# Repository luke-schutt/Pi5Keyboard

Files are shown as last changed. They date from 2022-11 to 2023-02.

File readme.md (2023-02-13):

# Pi5 Keyboard

A monoblock split 38-key keyboard inspired by the [ChocV](https://github.com/brickbots/chocV).

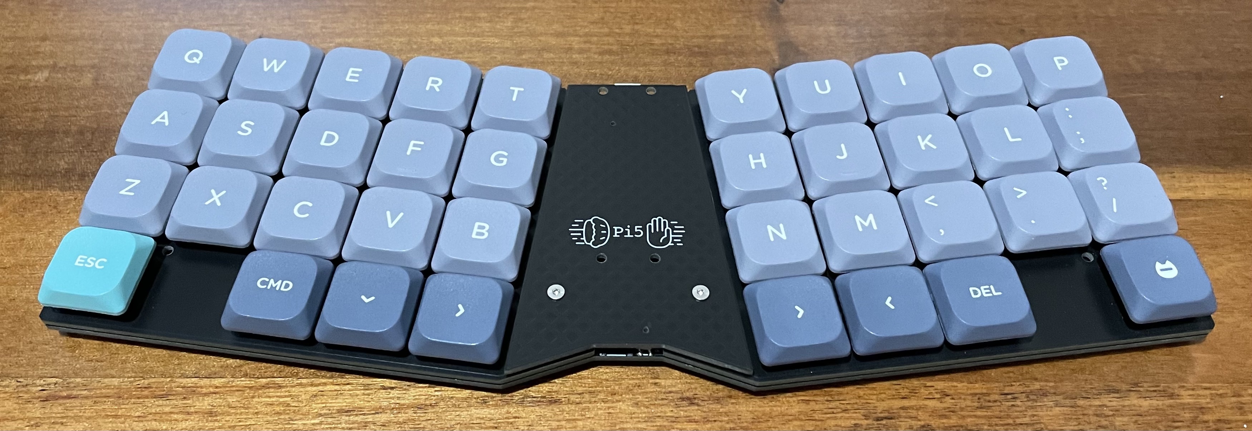
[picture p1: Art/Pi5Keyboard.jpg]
Keyboard


## Design

The keyboard consists of two boards, the main PCB and a mounting plate, and and optional MCU cover. The switches are on a 19x19mm grid with the footprint supporting Kailh Choc V1, V2, Gateron low profile, and MX switches.

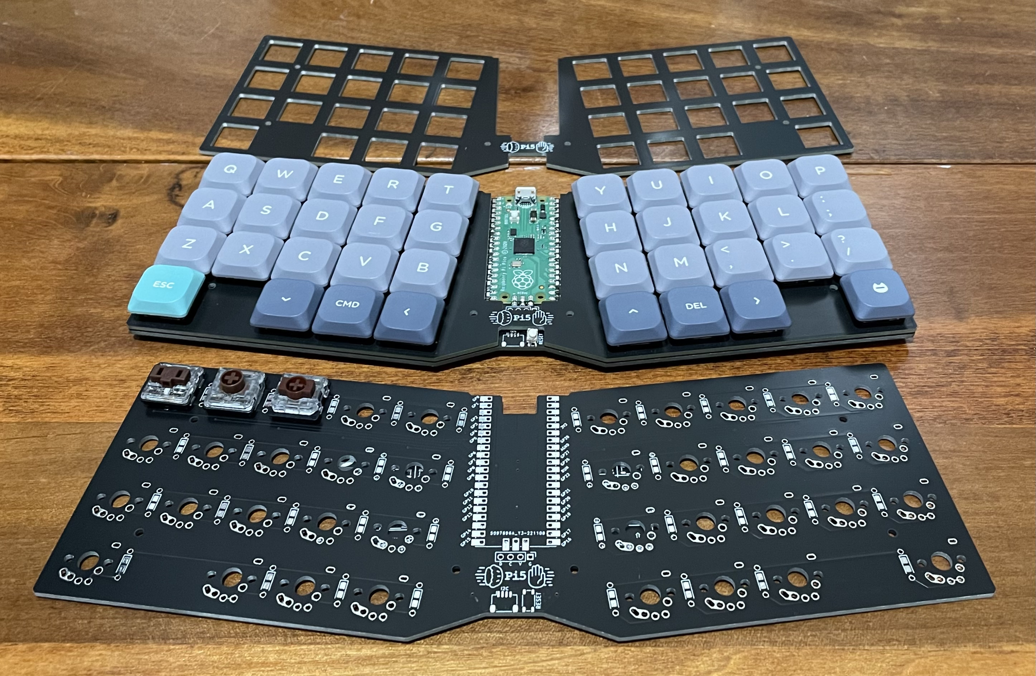
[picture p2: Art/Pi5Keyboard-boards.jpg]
Keyboard boards


The bottom of the board features footprints for a convenient reset switch and a JST connector with 3.3v and I2C data that (again, untested) should support [Qwiic](https://www.sparkfun.com/qwiic) or [STEMMA QT](https://learn.adafruit.com/introducing-adafruit-stemma-qt/what-is-stemma-qt) accessories.

The spacing between the PCB and plate with V2 Choc switches doesn't allow for SMD parts. Fortunately the diode footprint also allows though-hole components so they can be soldered under the PCB.

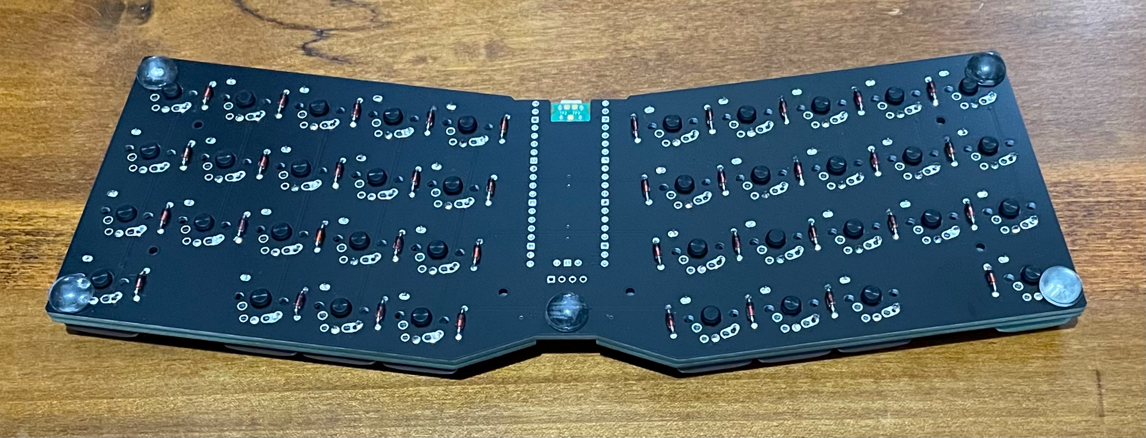
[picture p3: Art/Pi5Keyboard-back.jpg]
Keyboard back


## Build one!

Check out the [gerbers folder](Gerbers/) for zip files that can be uploaded to your PCB manufacturer of your choice.

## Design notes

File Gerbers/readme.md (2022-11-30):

# Gerbers!

Here you can find gerbers and revision history for the Pi5 Keyboard. Git commits are used for the KiCad revisions so if needed checkout the correct commit and make any desired modifications from that.

## Revision 1

Note: _This revision has **not** been tested!_

Revision 1 moves the PCB mounting holes to match the Raspberry Pi Pico's mounting holes and the reset button was moved a bit. Slots for diodes are added to the mounting plate. Holes were moved on the microcontroller cover.

The revision 0 mounting plate is compatible if slots for the diodes aren't desired, however it does have two mounting holes that aren't present. The microcontroller cover was retroactively created for revision 0 with mounting holes matching the Raspberry Pi Pico. Because of this it is also compatible with either design, however the two additional mounting holes were removed and the reset button hole was shifted to match revision 1.

- [main PCB rev1](Pi5-pcb-rev1.zip)
- [mounting plate rev1](Pi5-plate-rev1.zip)
- [controller cover rev1](Pi5-cover-rev1.zip)

## Revision 0

- [main PCB](Pi5-pcb-rev0.zip)
- [mounting plate](Pi5-plate-rev0.zip)
- [controller cover](Pi5-cover-rev0.zip)

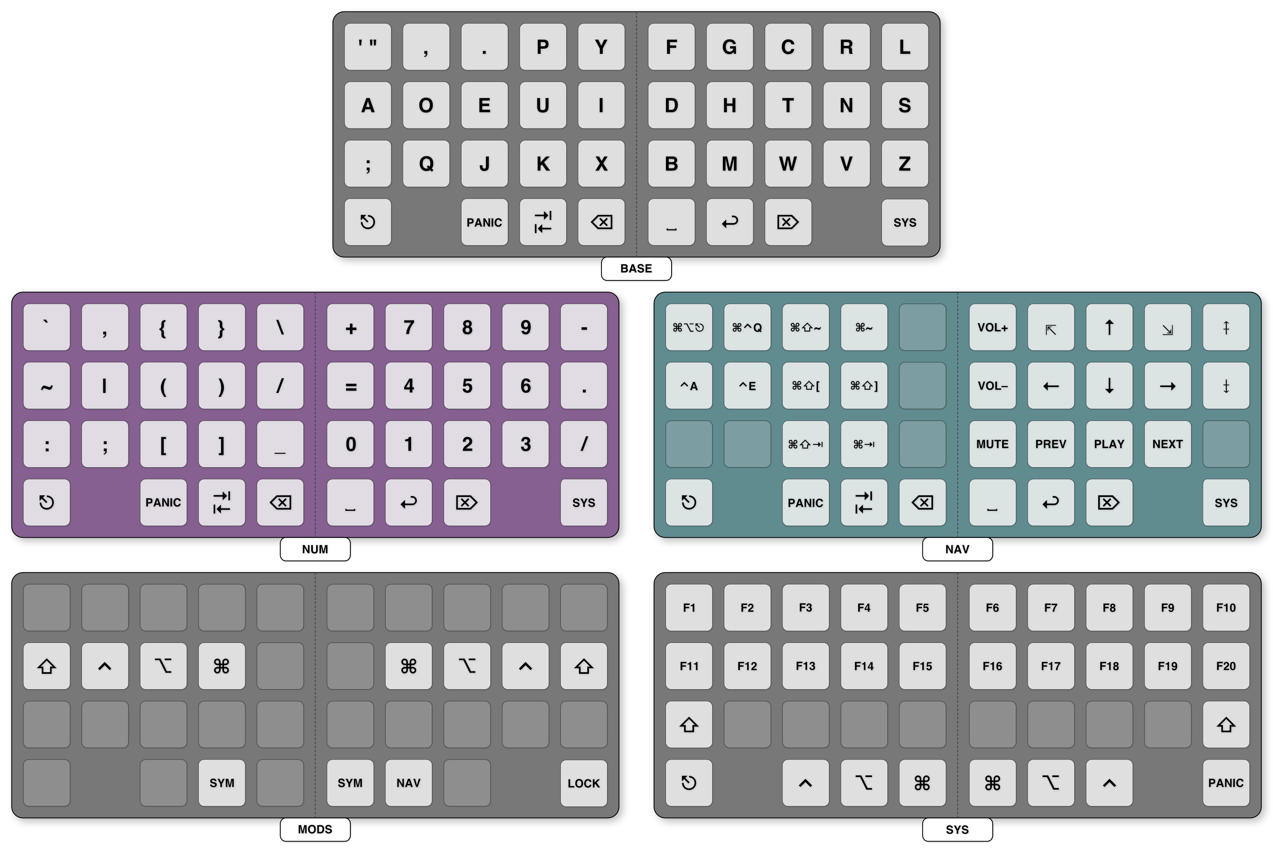
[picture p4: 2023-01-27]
Art/Layout.png

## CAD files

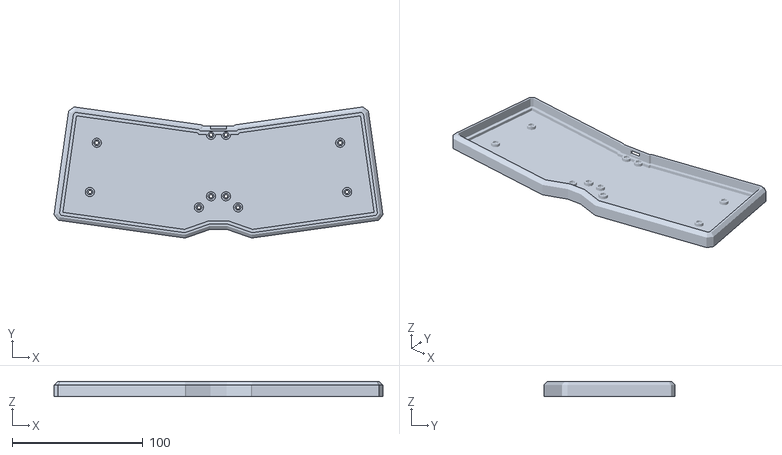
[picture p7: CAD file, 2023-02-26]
Case/case.stl
251.6 x 100.3 x 11.2

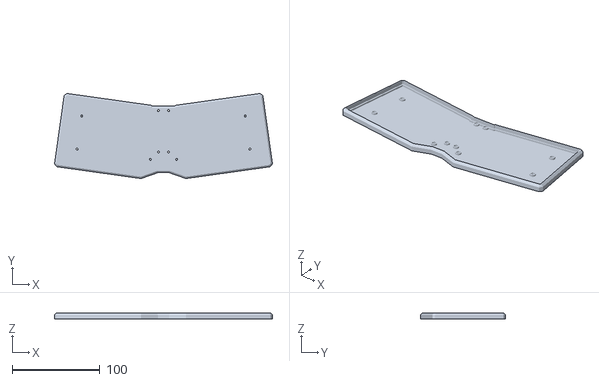
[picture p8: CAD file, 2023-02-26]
stl/case.stl
248.1 x 96.9 x 6.80

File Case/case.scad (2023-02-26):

include <chamfer_extrude.scad>;
$fn = 30;

// Thickness of the PCB.
$pcb_thickness = 7;
// Tolerance for fitting the PCB within the bezel.
$pcb_tolerance = 0.75;
// Width for the PCB lip.
$pcb_lip = 1.75;

// Desired cavity depth, excluding PCB.
$cavity_depth = 2.25;
// Case bottom thickness.
$bottom_thickness = 2;
// Case wall thickness above the PCB lip, at the thickest point.
$wall_thickness = 4;
// Full cavity depth.
cavity_well = $cavity_depth + $pcb_thickness;
// Full case height.
case_height = cavity_well + $bottom_thickness;

// If the top-outer edge should be chamfered.
$chamfer = true;
// The size of the chamfer.
$chamfer_size = 2.5;

// Mounting nut size.
$nut_size = 4.15;
// Mounting nut height.
$nut_height = 1.6;
// Mounting post radius.
$post_radius = 3.5;
// Mounting post hole radius.
$post_hole = 1.25;
// Mounting nut radius.
nut_radius = ($nut_size / 2) / cos(180 / 6);
// Vertical adjustment with the SVG Y inversion.
y_height = 8.5 * 25.4;
// Mounting post locations.
mounting_points = [
    // Pi Pico mounting holes.
    [136.8, y_height - 75.5],
    [148.2, y_height - 75.5],
    [136.8, y_height - 122.5],
    [148.2, y_height - 122.5],
    // Main mounting holes.
    [49.429641, y_height - 81.604177],
    [44.141063, y_height - 119.234364],
    [235.569953, y_height - 81.603467],
    [240.85853, y_height - 119.233654],
    // V0 mounting holes.
    [127.5, y_height - 131],
    [157.5, y_height - 131]
];
// Foot width.
foot_width = 12;
// Foot height.
foot_height = 1.75;
// Foot thickness.
foot_thickness = 1.25;
// Feet locations.
foot_positions = [
    [142.5, y_height - 118.5, 90],
    [114, y_height - 137.5, 90],
    [171, y_height - 137.5, 90],
    [41.5, y_height - 71, 0],
    [33.3, y_height - 128, 0],
    [243.5, y_height - 71, 0],
    [251.7, y_height - 128, 0]
];

// Import the PCB outline.
module pi5_pcb() {
    import(file = "pcb.svg");
}

// Mounting post negative.
module mounting_drill() {
    union() {
        // Post bolt hole.
        cylinder(h = cavity_well, r = $post_hole);
        // Post nut recess.
        translate([0, 0, (case_height - $pcb_thickness - $nut_height - 0.001)])
            cylinder(h = $nut_height + 0.002, r = nut_radius, $fn = 6);
    }
}

// Create a mounting positive.
module mounting_post() {
    cylinder(h = case_height - $pcb_thickness, r = $post_radius);
}

// Loop throguh mounting post positions.
module post_positions() {
    for (index = [0 : len(mounting_points) - 1]) {
        point = mounting_points[index];
        translate([point[0], point[1], 0])
            children();
    }
}

module foot_disc_recess() {
    cylinder(h = foot_thickness, r = 3.1, center = true);
}

union() {
    // Main case positive.
    difference() {
        // Main case shape.
        linear_extrude(height = case_height)
            offset(delta = $wall_thickness + $pcb_tolerance)
            pi5_pcb();
        // Case to subtract above the PCB lip.
        translate([0, 0, (case_height - $pcb_thickness)])
            linear_extrude(height = case_height)
            offset(delta = $pcb_tolerance)
            pi5_pcb();
        // Case to subtract making up the PCB lip.
        translate([0, 0, $bottom_thickness])
            linear_extrude(height = case_height)
            offset(delta = (0 - $pcb_lip))
            pi5_pcb();
        // Mounting post cutouts.
        post_positions()
            mounting_drill();
        // Add the chamfer.
        if ($chamfer) {
            translate([0, 0, (case_height - $chamfer_size + 0.001)])
                difference() {
                    linear_extrude(height = $chamfer_size)
                        offset(delta = $wall_thickness + $pcb_tolerance)
                        pi5_pcb();
                    chamfer_extrude(height = $chamfer_size, angle = 45, $fn = 10)
                        offset(delta = ($wall_thickness + $pcb_tolerance - $chamfer_size + 0.001))
                        pi5_pcb();
            }
        }
        // Subtract the area for USB.
        translate([142.5, 144, $bottom_thickness + $cavity_depth + 3.5])
            cube([8.5, 5, 3.5], center = true);
        translate([142.5, 147.5, $bottom_thickness + $cavity_depth + 3.5])
            cube([12.5, 5, 7.5], center = true);
        // Subtract positions for feet.
        for (index = [0 : len(foot_positions) - 1]) {
            foot_data = foot_positions[index];
            translate([foot_data[0], foot_data[1], 0])
                rotate([0, 0, foot_data[2]])
                cube([foot_width, foot_height, foot_thickness], center = true);
        }
        translate([33.411372, y_height - 127.319766, 0])
            foot_disc_recess();
        translate([251.588221, y_height - 127.319056, 0])
            foot_disc_recess();
        translate([41.344239, y_height - 70.874486, 0])
            foot_disc_recess();
        translate([243.655355, y_height - 70.873776, 0])
            foot_disc_recess();
    }
    // Mounting post positives.
    difference() {
        post_positions()
            mounting_post();
        post_positions()
            mounting_drill();
    }
}

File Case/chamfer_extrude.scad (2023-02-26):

module chamfer_extrude(height = 2, angle = 10, center = false) {
    /*
       chamfer_extrude - OpenSCAD operator module to approximate
        chamfered/tapered extrusion of a 2D path
    
       (C) 2019-02, Stewart Russell (scruss) - CC-BY-SA
    
       NOTE: generates _lots_ of facets, as many as
    
            6 * path_points + 4 * $fn - 4
    
       Consequently, use with care or lots of memory.
    
       Example:

            chamfer_extrude(height=5,angle=15,$fn=8)square(10);
    
       generates a 3D object 5 units high with top surface a
        10 x 10 square with sides flaring down and out at 15
        degrees with roughly rounded corners.
    
       Usage:
       
        chamfer_extrude (
            height  =   object height: should be positive
                            for reliable results               ,
            
            angle   =   chamfer angle: degrees                 ,
            
            center  =   false|true: centres object on z-axis [ ,
            
            $fn     =   smoothness of chamfer: higher => smoother
            ]
        ) ... 2D path(s) to extrude ... ;
        
       $fn in the argument list should be set between 6 .. 16:
            <  6 can result in striking/unwanted results
            > 12 is likely a waste of resources.
            
       Lower values of $fn can result in steeper sides than expected.
        
       Extrusion is not truly trapezoidal, but has a very thin
        (0.001 unit) parallel section at the base. This is a 
        limitation of OpenSCAD operators available at the time.
        
    */
    
    // shift base of 3d object to origin or
    //  centre at half height if center == true
    translate([ 0, 
                0, 
                (center == false) ? (height - 0.001) :
                                    (height - 0.002) / 2 ]) {
        minkowski() {
            // convert 2D path to very thin 3D extrusion
            linear_extrude(height = 0.001) {
                children();
            }
            // generate $fn-sided pyramid with apex at origin,
            // rotated "point-up" along the y-axis
            rotate(270) {
                rotate_extrude() {
                    polygon([
                        [ 0,                    0.001 - height  ],
                        [ height * tan(angle),  0.001 - height  ],
                        [ 0,                    0               ]
                    ]);
                }
            }
        }
    }
}

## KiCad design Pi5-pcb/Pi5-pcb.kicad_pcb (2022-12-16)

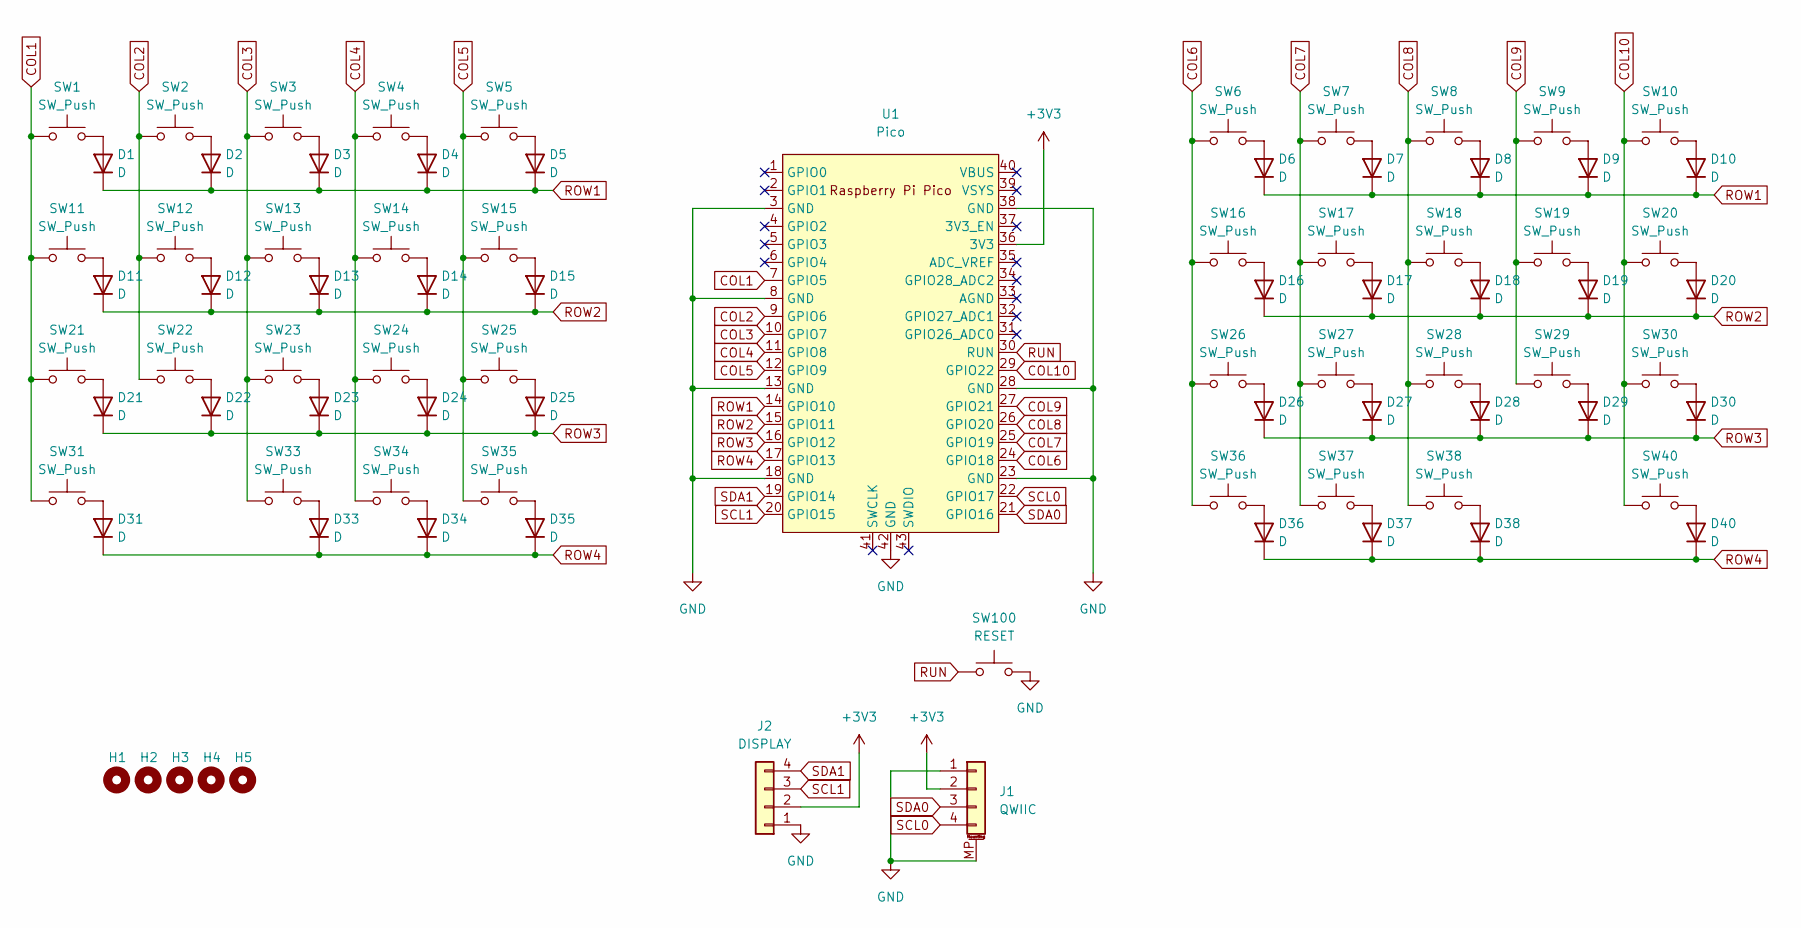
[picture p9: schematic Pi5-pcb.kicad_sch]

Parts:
D1, D2, D3, D4, D5, D6, D7, D8, D9, D10, D11, D12, D13, D14, D15, D16, D17, D18, D19, D20, D21, D22, D23, D24, D25, D26, D27, D28, D29, D30, D31, D33, D34, D35, D36, D37, D38, D40: D; Multi-diode
H1, H2, H3, H4: MountingHole_Pad; MountingHole_2.2mm_M2
H5: MountingHole_Pad; PiPico-Mounting
J1: QWIIC; JST_SH_SM04B-SRSS-TB_1x04-1MP_P1.00mm_Horizontal
J2: DISPLAY; PinHeader_1x04_P2.54mm_Vertical
SW1, SW2, SW3, SW4, SW5, SW6, SW7, SW8, SW9, SW10, SW11, SW12, SW13, SW14, SW15, SW16, SW17, SW18, SW19, SW20, SW21, SW22, SW23, SW24, SW25, SW26, SW27, SW28, SW29, SW30, SW31, SW33, SW34, SW35, SW36, SW37, SW38, SW40: SW_Push; Low Profile GC plus MX
SW100: RESET; Tact Switch (PTS815)
U1: Pico; PiPico

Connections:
+3V3: J1.2, J2.2, U1.36 (3V3)
COL1: SW1.1, SW11.1, SW21.1, SW31.1, U1.7 (GPIO5)
COL2: SW2.1, SW12.1, SW22.1, U1.9 (GPIO6)
COL3: SW3.1, SW13.1, SW23.1, SW33.1, U1.10 (GPIO7)
COL4: SW4.1, SW14.1, SW24.1, SW34.1, U1.11 (GPIO8)
COL5: SW5.1, SW15.1, SW25.1, SW35.1, U1.12 (GPIO9)
COL6: SW6.1, SW16.1, SW26.1, SW36.1, U1.24 (GPIO18)
COL7: SW7.1, SW17.1, SW27.1, SW37.1, U1.25 (GPIO19)
COL8: SW8.1, SW18.1, SW28.1, SW38.1, U1.26 (GPIO20)
COL9: SW9.1, SW19.1, SW29.1, U1.27 (GPIO21)
COL10: SW10.1, SW20.1, SW30.1, SW40.1, U1.29 (GPIO22)
GND: J1.1, J1.MP (MountPin), J2.1, SW100.2, U1.3 (GND), U1.8 (GND), U1.13 (GND), U1.18 (GND), U1.23 (GND), U1.28 (GND), U1.38 (GND), U1.42 (GND)
unnamed: D1.2 (A), SW1.2
unnamed: D2.2 (A), SW2.2
unnamed: D3.2 (A), SW3.2
unnamed: D4.2 (A), SW4.2
unnamed: D5.2 (A), SW5.2
unnamed: D6.2 (A), SW6.2
unnamed: D7.2 (A), SW7.2
unnamed: D8.2 (A), SW8.2
unnamed: D9.2 (A), SW9.2
unnamed: D10.2 (A), SW10.2
unnamed: D11.2 (A), SW11.2
unnamed: D12.2 (A), SW12.2
unnamed: D13.2 (A), SW13.2
unnamed: D14.2 (A), SW14.2
unnamed: D15.2 (A), SW15.2
unnamed: D16.2 (A), SW16.2
unnamed: D17.2 (A), SW17.2
unnamed: D18.2 (A), SW18.2
unnamed: D19.2 (A), SW19.2
unnamed: D20.2 (A), SW20.2
unnamed: D21.2 (A), SW21.2
unnamed: D22.2 (A), SW22.2
unnamed: D23.2 (A), SW23.2
unnamed: D24.2 (A), SW24.2
unnamed: D25.2 (A), SW25.2
unnamed: D26.2 (A), SW26.2
unnamed: D27.2 (A), SW27.2
unnamed: D28.2 (A), SW28.2
unnamed: D29.2 (A), SW29.2
unnamed: D30.2 (A), SW30.2
unnamed: D31.2 (A), SW31.2
unnamed: D33.2 (A), SW33.2
unnamed: D34.2 (A), SW34.2
unnamed: D35.2 (A), SW35.2
unnamed: D36.2 (A), SW36.2
unnamed: D37.2 (A), SW37.2
unnamed: D38.2 (A), SW38.2
unnamed: D40.2 (A), SW40.2
ROW1: D1.1 (K), D2.1 (K), D3.1 (K), D4.1 (K), D5.1 (K), D6.1 (K), D7.1 (K), D8.1 (K), D9.1 (K), D10.1 (K), U1.14 (GPIO10)
ROW2: D11.1 (K), D12.1 (K), D13.1 (K), D14.1 (K), D15.1 (K), D16.1 (K), D17.1 (K), D18.1 (K), D19.1 (K), D20.1 (K), U1.15 (GPIO11)
ROW3: D21.1 (K), D22.1 (K), D23.1 (K), D24.1 (K), D25.1 (K), D26.1 (K), D27.1 (K), D28.1 (K), D29.1 (K), D30.1 (K), U1.16 (GPIO12)
ROW4: D31.1 (K), D33.1 (K), D34.1 (K), D35.1 (K), D36.1 (K), D37.1 (K), D38.1 (K), D40.1 (K), U1.17 (GPIO13)
RUN: SW100.1, U1.30 (RUN)
SCL0: J1.4, U1.22 (GPIO17)
SCL1: J2.3, U1.20 (GPIO15)
SDA0: J1.3, U1.21 (GPIO16)
SDA1: J2.4, U1.19 (GPIO14)

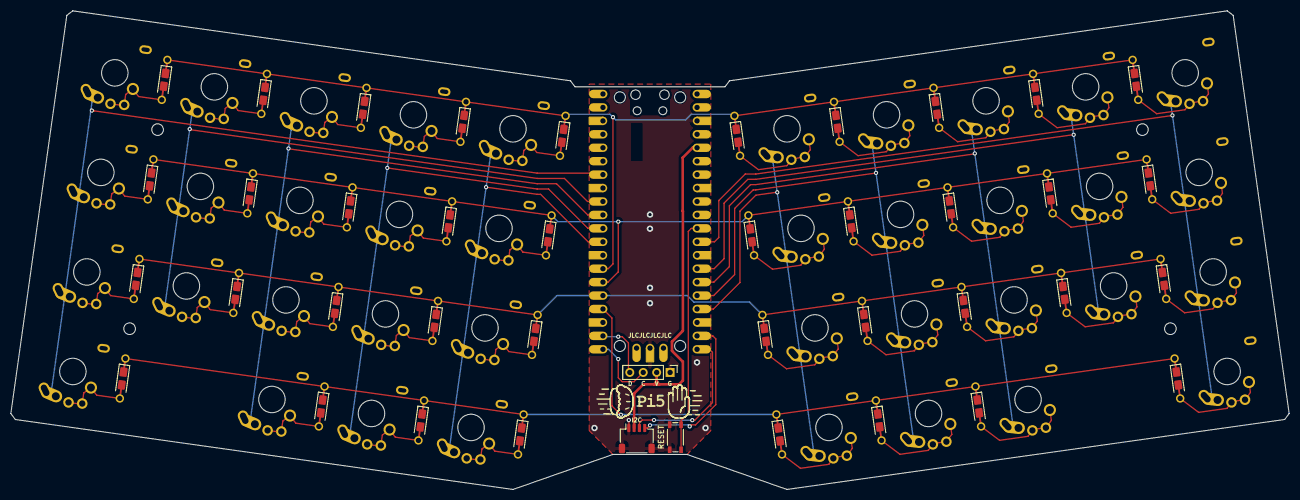
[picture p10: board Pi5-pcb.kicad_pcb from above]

Board: 2 copper layers, 241.6 x 90.5 mm, 85 parts (0 on the bottom side), 59 nets.

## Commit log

2022-11-25 Initial commit.
    [Pi5-pcb.kicad_pcb, Pi5-pcb.kicad_sch, Pi5-plate.kicad_pcb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]
2022-11-25 Pi5 Keyboard revision 1.
    [Pi5-pcb.kicad_pcb, Pi5-pcb.kicad_sch, Pi5-plate.kicad_pcb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]
2022-11-30 Added controller cover to plate project including a retroactive rev0 design.
    [Controller-cover.kicad_pcb]
2022-12-16 Moved custom footprints into Pi5 footprint library.
    [Pi5-pcb.kicad_pcb, Pi5-pcb.kicad_sch]
2023-02-26 Added OpenSCAD case design.
    [case.scad, case.stl, chamfer_extrude.scad]
